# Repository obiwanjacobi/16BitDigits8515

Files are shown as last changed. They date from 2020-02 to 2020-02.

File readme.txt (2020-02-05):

This project is a four-digit 7-segments display that decodes 16-bit of data into a hexadecimal notation.

Uses an ATmega8515 to read the 16 input bits and multiplex a common cathode 4-digit 7-segment display.

Folders:
--------
KiCad	                  - contains the schematic and a rough board layout.
FourSevenSegment8515      - contains the Arduino sketch for the ATmega8515 with instructions how to program.

Discussed on EEVBlog Forum: https://www.eevblog.com/forum/projects/16-bit-to-4-digit-7-segment-decoder

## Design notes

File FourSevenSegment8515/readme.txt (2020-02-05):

Install MajorCore into the Arduino IDE
--------------------------------------
https://github.com/MCUdude/MajorCore

File->Preferences=>Additional Boards Manager Urls: https://mcudude.github.io/MajorCore/package_MCUdude_MajorCore_index.json

Tools->Board->Boards Manager...
	Type [V]: Contributed
	Find MCUDude => Install

Tools->Board->[MajorCore] Atmega8515

The code should now compile (check button)

Use an Arduino Uno as an ISP (programmer).
------------------------------------------

Tools->Programmer: Arduino as ISP
Tools->Clock: 8Mhz Internal
Tools->Bootloader: No bootloader

Follow this tutorial to connect the ATmega8515 to the Arduino ISP:
https://www.arduino.cc/en/Tutorial/ArduinoISP

On the Arduino Uno used as an ISP:
Pin 10 = Reset
Pin 11 = MOSI
Pin 12 = MISO
Pin 13 = SCK
GND => GND
+5V => +5V

To upload the program to the ATmega8515:
Sketch->Upload Using Programmer

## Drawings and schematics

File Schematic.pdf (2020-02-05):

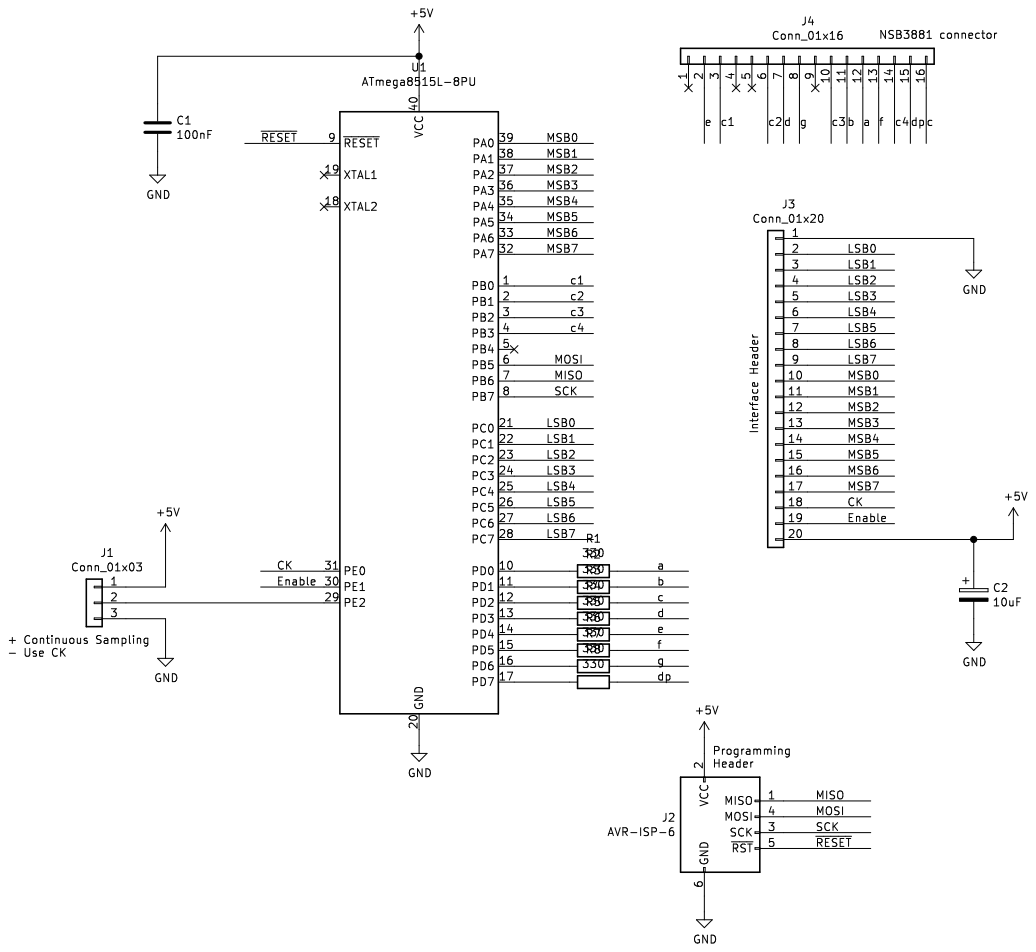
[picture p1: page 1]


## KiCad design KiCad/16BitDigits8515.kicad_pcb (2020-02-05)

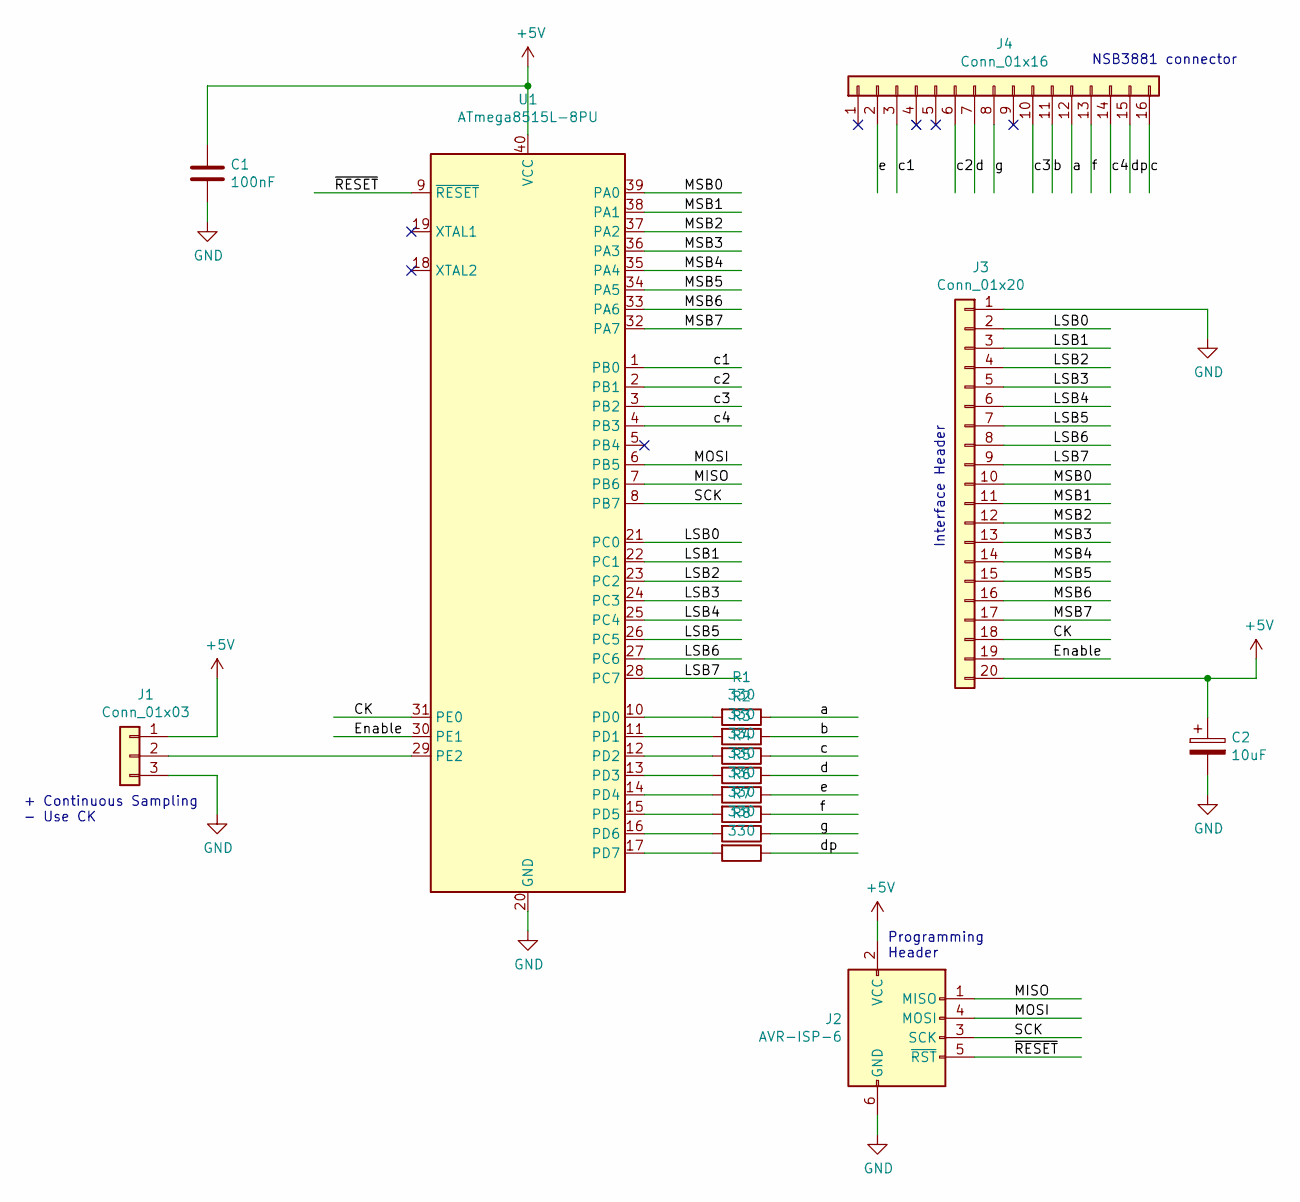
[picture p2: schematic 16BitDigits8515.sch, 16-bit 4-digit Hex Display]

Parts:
C1: 100nF; C_Rect_L9.0mm_W2.5mm_P7.50mm_MKT
C2: 10uF; CP_Radial_D5.0mm_P2.50mm
J1: Conn_01x03; PinHeader_1x03_P2.54mm_Vertical
J2: AVR-ISP-6; PinHeader_2x03_P2.54mm_Vertical
J3: Conn_01x20; PinHeader_1x20_P2.54mm_Vertical
J4: Conn_01x16; PinHeader_1x16_P2.54mm_Vertical
R1, R2, R3, R4, R5, R6, R7, R8: 330; R_Axial_DIN0207_L6.3mm_D2.5mm_P10.16mm_Horizontal
U1: ATmega8515L-8PU; DIP-40_W15.24mm

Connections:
+5V: C1.1, C2.1, J1.1, J2.2 (VCC), J3.20, U1.40 (VCC)
/CK: J3.18, U1.31 (PE0)
/Enable: J3.19, U1.30 (PE1)
/LSB0: J3.2, U1.21 (PC0)
/LSB1: J3.3, U1.22 (PC1)
/LSB2: J3.4, U1.23 (PC2)
/LSB3: J3.5, U1.24 (PC3)
/LSB4: J3.6, U1.25 (PC4)
/LSB5: J3.7, U1.26 (PC5)
/LSB6: J3.8, U1.27 (PC6)
/LSB7: J3.9, U1.28 (PC7)
/MISO: J2.1 (MISO), U1.7 (PB6)
/MOSI: J2.4 (MOSI), U1.6 (PB5)
/MSB0: J3.10, U1.39 (PA0)
/MSB1: J3.11, U1.38 (PA1)
/MSB2: J3.12, U1.37 (PA2)
/MSB3: J3.13, U1.36 (PA3)
/MSB4: J3.14, U1.35 (PA4)
/MSB5: J3.15, U1.34 (PA5)
/MSB6: J3.16, U1.33 (PA6)
/MSB7: J3.17, U1.32 (PA7)
/SCK: J2.3 (SCK), U1.8 (PB7)
/a: J4.12, R1.1
/b: J4.11, R2.1
/c: J4.16, R3.1
/c1: J4.3, U1.1 (PB0)
/c2: J4.6, U1.2 (PB1)
/c3: J4.10, U1.3 (PB2)
/c4: J4.14, U1.4 (PB3)
/d: J4.7, R4.1
/dp: J4.15, R8.1
/e: J4.2, R5.1
/f: J4.13, R6.1
/g: J4.8, R7.1
/~RESET: J2.5 (~RST), U1.9 (~RESET)
GND: C1.2, C2.2, J1.3, J2.6 (GND), J3.1, U1.20 (GND)
unnamed: J1.2, U1.29 (PE2)
unnamed: R1.2, U1.10 (PD0)
unnamed: R2.2, U1.11 (PD1)
unnamed: R3.2, U1.12 (PD2)
unnamed: R4.2, U1.13 (PD3)
unnamed: R5.2, U1.14 (PD4)
unnamed: R6.2, U1.15 (PD5)
unnamed: R7.2, U1.16 (PD6)
unnamed: R8.2, U1.17 (PD7)

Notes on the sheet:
NSB3881 connector
+ Continuous Sampling - Use CK
Interface Header
Programming Header

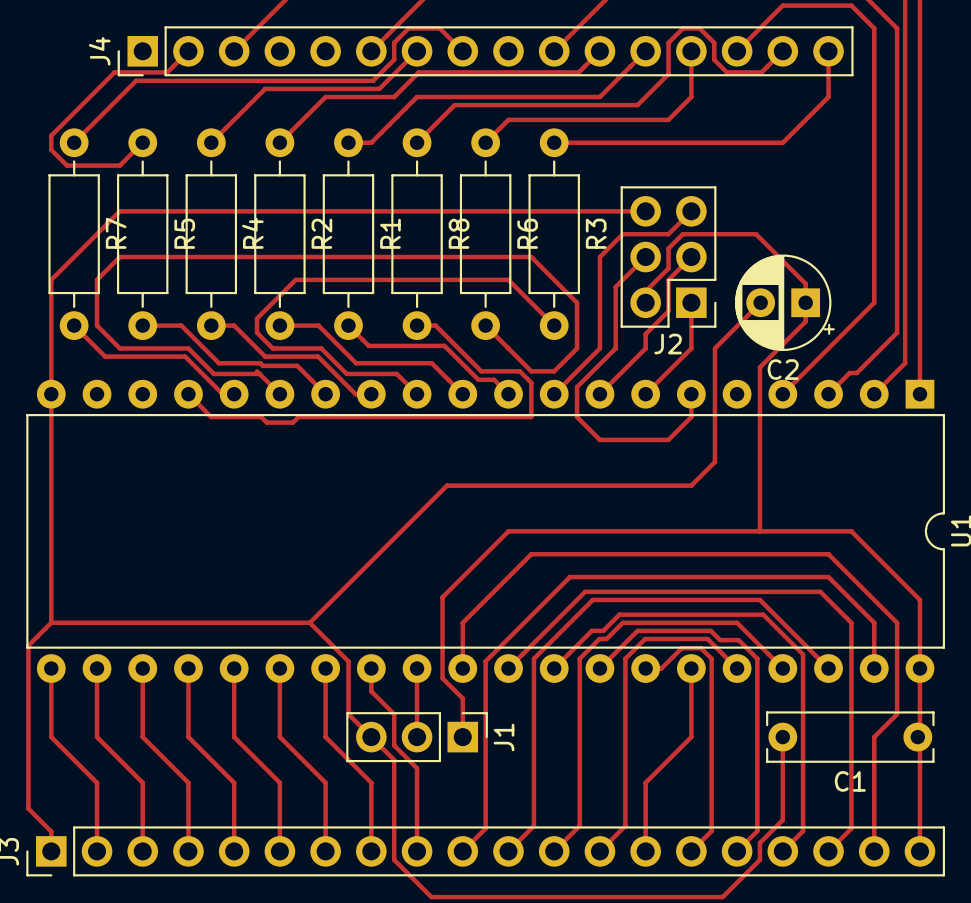
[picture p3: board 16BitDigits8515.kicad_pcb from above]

Board: 2 copper layers, 15 parts (0 on the bottom side), 45 nets.

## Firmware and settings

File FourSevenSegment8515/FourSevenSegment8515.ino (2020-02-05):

const uint8_t DecoderTable_size = 17;
uint8_t DecoderTable[DecoderTable_size] =
    {
        0b10000000,
        0b01111110,
        0b00110000,
        0b01101101,
        0b01111001,
        0b00110011,
        0b01011011,
        0b01011111,
        0b01110000,
        0b01111111,
        0b01110011,
        0b01110111,
        0b00011111,
        0b01001110,
        0b00111101,
        0b01001111,
        0b01000111,
};

uint8_t decode7(uint8_t value)
{
  if (value >= DecoderTable_size)
    return DecoderTable[0];

  return DecoderTable[value + 1];
}

void outputDigit4(uint8_t value, int digit)
{
  uint8_t cathode = ~(1 << digit) & 0x0F;
  uint8_t b = (PORTB & 0xF0);

  PORTD = 0;
  PORTB = b | cathode;
  PORTD = decode7(value);
}

// digit values that will be displayed
// timer interrupt will drive 7-seg
const uint8_t digitValue_size = 4;
// 0-3 => left to right
volatile uint8_t _digitValue[digitValue_size];

// what digit are we writing?
volatile uint8_t _digitIndex;

// called when ORC1A is reached
ISR(TIMER1_COMPA_vect)
{
  outputDigit4(_digitValue[_digitIndex], _digitIndex);

  if (_digitIndex < digitValue_size)
  {
    _digitIndex++;
  }
  else
  {
    _digitIndex = 0;
  }
}

void setupTimer()
{
  OCR1A = 0x1FF;
  TCCR1B |= 0b010;        // prescaler: CS1[2:0]
  TCCR1B |= (1 << WGM12); // CTC mode
  TIMSK |= (1 << OCIE1A); // enable interrupt
}

void setupPorts()
{
  // input sampling ports
  DDRA = 0;
  DDRC = 0;

  // 7-seg drivers
  DDRB |= 0x0F;
  DDRD = 255;
}

void setup()
{
  setupTimer();
  setupPorts();
  sei();
}

void printDigit16(uint8_t msb, uint8_t lsb)
{
  _digitValue[0] = msb >> 4;
  _digitValue[1] = msb & 0x0F;
  _digitValue[2] = lsb >> 4;
  _digitValue[3] = lsb & 0x0F;
}

void loop()
{
  uint8_t msb = PINA;
  uint8_t lsb = PINC;

  printDigit16(msb, lsb);
}

int main()
{
  setup();
  while (true)
  {
    loop();
  }
}
